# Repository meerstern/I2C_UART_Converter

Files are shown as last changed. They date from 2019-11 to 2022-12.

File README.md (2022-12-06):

# I2C_UART_Converter
I2C-UART Converter with Grove Connector

## 概要 
  * マイコンのI2CポートをUART通信ポートに変換するアダプタです
  * マイコンからI2Cデバイスとして制御し、UARTのボーレート設定、送信、受信処理をすることができます
  * I2C/UARTプロトコルブリッジ[SC16IS740][1]を搭載しています
  * I2CはGrove互換コネクタとなっており、3.3V/５Vの電源、通信に対応しています
  * I2C/UARTプロトコルブリッジSC16IS740は64bytesのバッファを内蔵しています
  * 7.3728MHzの水晶発振子を搭載しており、マイコンのメインクロックから独立してUARTのボーレート設定ができます  
  * デフォルトI2Cアドレスは8bit:0x9A(7bit:0x4D)です  

## 注意 
  * Arduino Uno以外の場合はサンプルコード内SC16IS750.cppの29行目付近のWire定義を必要に応じて変更してください  

## 販売サイト
  * [スイッチサイエンス][2]

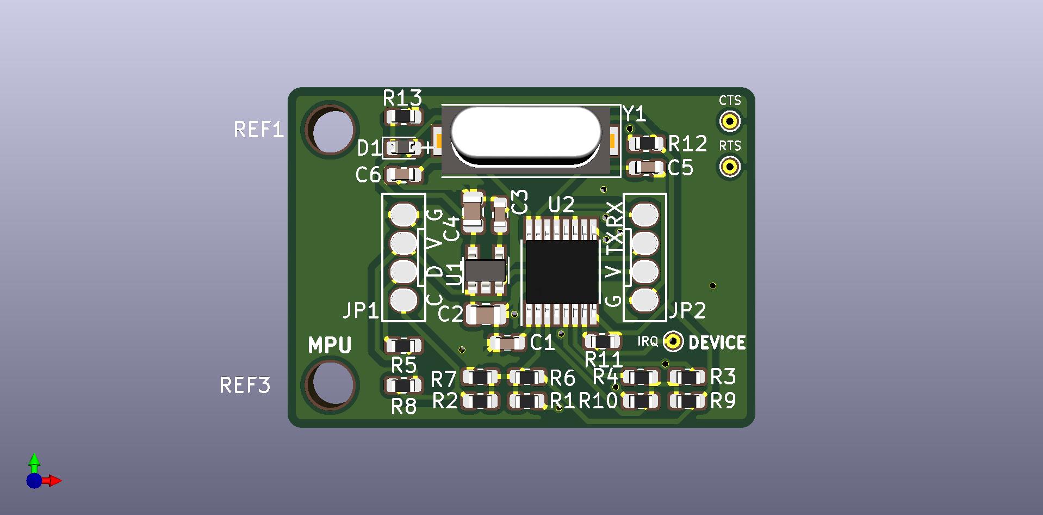
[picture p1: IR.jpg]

   
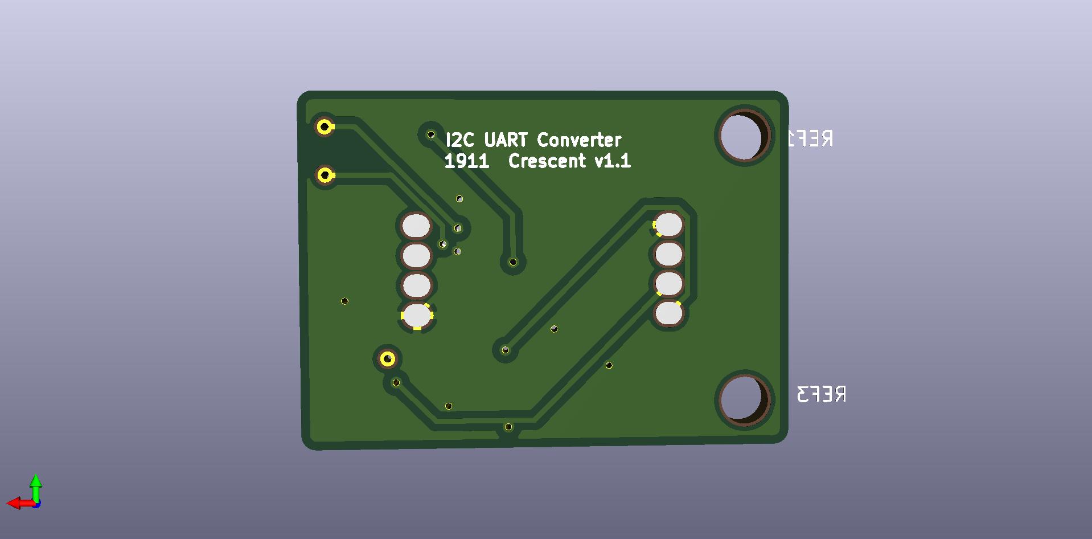
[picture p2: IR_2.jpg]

    
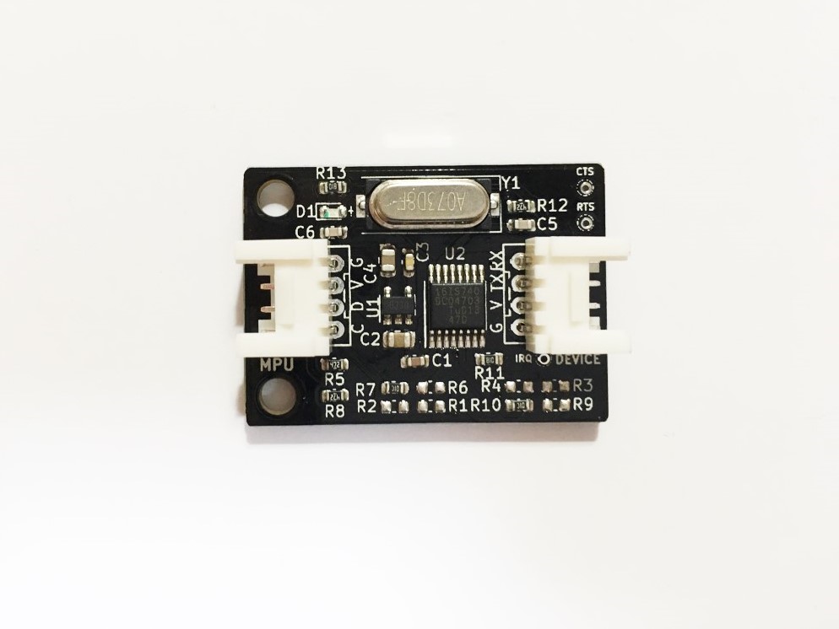
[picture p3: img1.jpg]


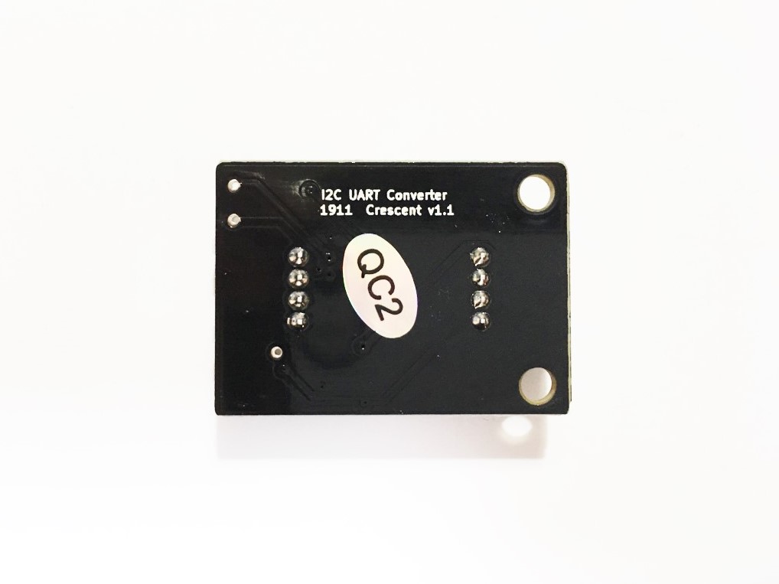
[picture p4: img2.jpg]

    
[1]: https://www.nxp.com/products/peripherals-and-logic/signal-chain/bridges/single-uart-with-i2c-bus-spi-interface-64-bytes-of-transmit-and-receive-fifos-irda-sir-built-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 "*1"
[2]: https://www.switch-science.com/products/6027
MIT Lisense

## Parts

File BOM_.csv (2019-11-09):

ID | 参照記号 | パッケージ | 数 | 名称 | Supplier and ref
2 | JP1,JP2 | GROVE | 2 | PINHD-1X4
3 | C1 | C_0603_1608Metric | 1 | 0.1u | C15725
4 | C2,C4 | C_0805_2012Metric | 2 | 10u | C15850
5 | C3 | C_0603_1608Metric | 1 | 0.01u | C57112
6 | C5,C6 | C_0603_1608Metric | 2 | 10p | C1634
7 | D1 | D_0603_1608Metric | 1 | LED | C72041
8 | R7,R10 | R_0603_1608Metric | 8 | 0
9 | R5,R8,R12 | R_0603_1608Metric | 3 | 4.7k
10 | R11,R13 | R_0603_1608Metric | 2 | 1k
11 | U1 | SOT-23-5 | 1 | LD3985M33R_SOT23
12 | Y1 | Crystal_SMD_HC49-SD | 1 | Crystal
16 | U2 | TSSOP-16_4.4x5mm_Pitch0.65mm | 1 | SC16IS740IPW

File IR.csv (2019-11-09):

ID | 参照記号 | パッケージ | 数 | 名称 | Supplier and ref
1 | REF3,REF1 | MountingHole_3.2mm_M3 | 2 | MountingHole_3.2mm_M3
2 | JP1,JP2 | GROVE | 2 | PINHD-1X4
3 | C1 | C_0603_1608Metric | 1 | 0.1u
4 | C2,C4 | C_0805_2012Metric | 2 | 10u
5 | C3 | C_0603_1608Metric | 1 | 0.01u
6 | C5,C6 | C_0603_1608Metric | 2 | 10p
7 | D1 | D_0603_1608Metric | 1 | LED
8 | R1,R2,R3,R4,R6,R7,R9,R10 | R_0603_1608Metric | 8 | 0
9 | R5,R8,R12 | R_0603_1608Metric | 3 | 4.7k
10 | R11,R13 | R_0603_1608Metric | 2 | 1k
11 | U1 | SOT-23-5 | 1 | LD3985M33R_SOT23
12 | Y1 | Crystal_SMD_HC49-SD | 1 | Crystal
13 | IRQ | TestPoint_THTPad_D1.0mm_Drill0.5mm | 1 | IRQ
14 | CTS | TestPoint_THTPad_D1.0mm_Drill0.5mm | 1 | CTS
15 | RTS | TestPoint_THTPad_D1.0mm_Drill0.5mm | 1 | RTS
16 | U2 | TSSOP-16_4.4x5mm_Pitch0.65mm | 1 | SC16IS740IPW

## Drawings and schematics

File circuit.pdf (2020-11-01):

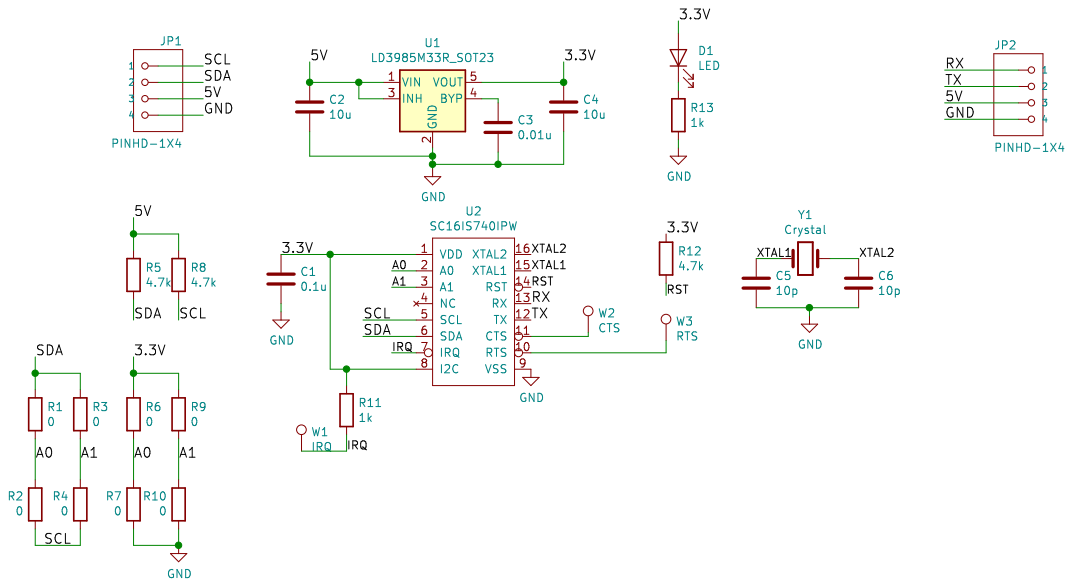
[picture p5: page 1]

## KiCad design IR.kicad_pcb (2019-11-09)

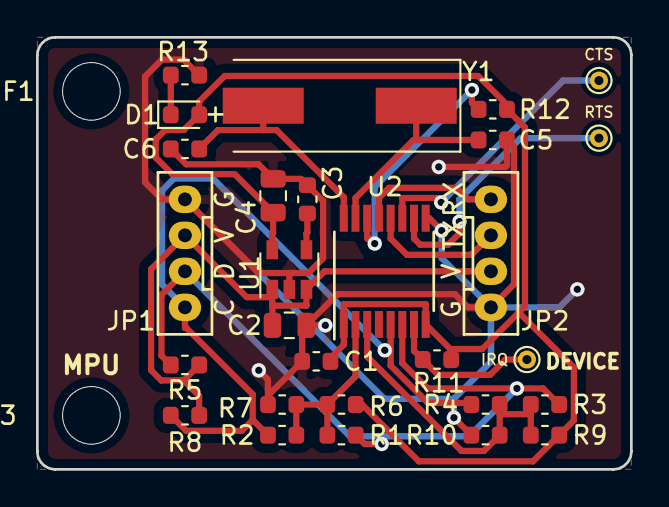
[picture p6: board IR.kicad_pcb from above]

Board: 2 copper layers, 33.0 x 24.0 mm, 30 parts (0 on the bottom side), 17 nets.

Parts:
C1: 0.1u; C_0603_1608Metric
C2, C4: 10u; C_0805_2012Metric
C3: 0.01u; C_0603_1608Metric
C5, C6: 10p; C_0603_1608Metric
CTS: CTS; TestPoint_THTPad_D1.0mm_Drill0.5mm
D1: LED; D_0603_1608Metric
IRQ: IRQ; TestPoint_THTPad_D1.0mm_Drill0.5mm
JP1, JP2: PINHD-1X4; GROVE
R1, R2, R3, R4, R6, R7, R9, R10: 0; R_0603_1608Metric
R5, R8, R12: 4.7k; R_0603_1608Metric
R11, R13: 1k; R_0603_1608Metric
REF1, REF3: MountingHole_3.2mm_M3
RTS: RTS; TestPoint_THTPad_D1.0mm_Drill0.5mm
U1: LD3985M33R_SOT23; SOT-23-5
U2: SC16IS740IPW; TSSOP-16_4.4x5mm_Pitch0.65mm
Y1: Crystal; Crystal_SMD_HC49-SD

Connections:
/3.3V: C1.1, C4.1, D1.2, R6.1, R9.1, R11.1, R12.1, U1.5, U2.1, U2.8
/5V: C2.1, JP1.3, JP2.3, R5.1, R8.1, U1.1, U1.3
/A0: R1.2, R2.2, R6.2, R7.2, U2.2
/A1: R3.2, R4.2, R9.2, R10.2, U2.3
/IRQ: IRQ.1, R11.2, U2.7
/RST: R12.2, U2.14
/RX: JP2.1, U2.13
/SCL: JP1.1, R2.1, R4.1, R8.2, U2.5
/SDA: JP1.2, R1.1, R3.1, R5.2, U2.6
/TX: JP2.2, U2.12
/XTAL1: C5.1, U2.15, Y1.1
/XTAL2: C6.1, U2.16, Y1.2
GND: C1.2, C2.2, C3.2, C4.2, C5.2, C6.2, JP1.4, JP2.4, R7.1, R10.1, R13.2, U1.2, U2.9
unnamed: C3.1, U1.4
unnamed: D1.1, R13.1
unnamed: RTS.1, U2.10
unnamed: CTS.1, U2.11

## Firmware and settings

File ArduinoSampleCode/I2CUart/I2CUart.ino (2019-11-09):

#include <Wire.h>

#include <string.h>
#include <SPI.h>
#include "SC16IS750.h"


SC16IS750 i2cuart = SC16IS750(SC16IS750_PROTOCOL_I2C,SC16IS750_ADDRESS_BB);

//Connect TX and RX with a wire and run this sketch

void setup() 
{
    Serial.begin(9600);

    // UART to Serial Bridge Initialization
    i2cuart.begin(9600);               //baudrate setting
    Serial.println("Init OK");
    if (i2cuart.ping()!=1) {
        Serial.println("device not found");
        while(1);
    } else {
        Serial.println("device found");
    }
    Serial.println("start serial communication");
    


};

void loop() 
{
   
    i2cuart.write(0x55);
    while(i2cuart.available()==0);
    if (i2cuart.read()!=0x55) {
        Serial.println("serial communication error 1");
        while(1);
    }
    else{
      Serial.println("serial communication OK 1");
    }   
    delay(500);
    
    i2cuart.write(0x0A);
    while(i2cuart.available()==0);
    if (i2cuart.read()!=0x0A) {
        Serial.println("serial communication error 2");
        while(1);
    }
    else{
      Serial.println("serial communication OK 2");
    }   
    
    delay(500);
      
     
  
  

  
};

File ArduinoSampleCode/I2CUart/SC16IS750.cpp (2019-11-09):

/*
Description:
This is a example code for Sandbox Electronics' I2C/SPI to UART bridge module.
You can get one of those products on
http://sandboxelectronics.com

Version:
V0.1

Release Date:
2014-02-16

Author:
Tiequan Shao          info@sandboxelectronics.com

Lisence:
CC BY-NC-SA 3.0

Please keep the above information when you use this code in your project.
*/


//#define SC16IS750_DEBUG_PRINT
#include "SC16IS750.h"
#include <SPI.h>
#include <Wire.h>


#ifdef __AVR__
 #define WIRE Wire
#else // Arduino Due
 #define WIRE Wire1
#endif


SC16IS750::SC16IS750(uint8_t prtcl, uint8_t addr_sspin)
{
    protocol = prtcl;
    if ( protocol == SC16IS750_PROTOCOL_I2C ) {
		device_address_sspin = (addr_sspin>>1);
	} else {
		device_address_sspin = addr_sspin;
	}
	peek_flag = 0;
//	timeout = 1000;
}


void SC16IS750::begin(uint32_t baud)
{
  //Serial.println("1111111111111111");
	if ( protocol == SC16IS750_PROTOCOL_I2C) {
	      //Serial.println("22222222222222");
        WIRE.begin();
    } else {
	//Serial.println("3333333333333333333");
		::pinMode(device_address_sspin, OUTPUT);
   	    ::digitalWrite(device_address_sspin, HIGH);
		SPI.setDataMode(SPI_MODE0);
		SPI.setClockDivider(SPI_CLOCK_DIV4);
		SPI.setBitOrder(MSBFIRST);
		SPI.begin();
		//SPI.setClockDivider(32);

	//Serial.println("4444444444444444444");
	};
    ResetDevice();
    FIFOEnable(1);
	  SetBaudrate(baud);
    SetLine(8,0,1);
}

int SC16IS750::available(void)
{
    return FIFOAvailableData();
}

int SC16IS750::read(void)
{
	if ( peek_flag == 0) {
		return ReadByte();
	} else {
		peek_flag = 0;
		return peek_buf;
	}
}

size_t SC16IS750::write(uint8_t val)
{
    WriteByte(val);
}

void SC16IS750::pinMode(uint8_t pin, uint8_t i_o)
{
    GPIOSetPinMode(pin, i_o);
}

void SC16IS750::digitalWrite(uint8_t pin, uint8_t value)
{
    GPIOSetPinState(pin, value);
}

uint8_t SC16IS750::digitalRead(uint8_t pin)
{
   return GPIOGetPinState(pin);
}


uint8_t SC16IS750::ReadRegister(uint8_t reg_addr)
{
    uint8_t result;
	if ( protocol == SC16IS750_PROTOCOL_I2C ) {  // register read operation via I2C

		WIRE.beginTransmission(device_address_sspin);
		WIRE.write((reg_addr<<3));
  	WIRE.endTransmission(0);
		WIRE.requestFrom(device_address_sspin,(uint8_t)1);
		result = WIRE.read();
	} else if (protocol == SC16IS750_PROTOCOL_SPI) {                                   //register read operation via SPI
		::digitalWrite(device_address_sspin, LOW);
		delayMicroseconds(10);
		SPI.transfer(0x80|(reg_addr<<3));
		result = SPI.transfer(0xff);
		delayMicroseconds(10);
		::digitalWrite(device_address_sspin, HIGH);
	}

	return result;

}

void SC16IS750::WriteRegister(uint8_t reg_addr, uint8_t val)
{
    if ( protocol == SC16IS750_PROTOCOL_I2C ) {  // register read operation via I2C
		WIRE.beginTransmission(device_address_sspin);
		WIRE.write((reg_addr<<3));
  	WIRE.write(val);
		WIRE.endTransmission(1);
	} else {
		::digitalWrite(device_address_sspin, LOW);
		delayMicroseconds(10);
		SPI.transfer(reg_addr<<3);
		SPI.transfer(val);
		delayMicroseconds(10);
		::digitalWrite(device_address_sspin, HIGH);

	}


    return ;
}

int16_t SC16IS750::SetBaudrate(uint32_t baudrate) //return error of baudrate parts per thousand
{
    uint16_t divisor;
    uint8_t prescaler;
    uint32_t actual_baudrate;
    int16_t error;
    uint8_t temp_lcr;
    if ( (ReadRegister(SC16IS750_REG_MCR)&0x80) == 0) { //if prescaler==1
        prescaler = 1;
    } else {
        prescaler = 4;
    }

    divisor = (SC16IS750_CRYSTCAL_FREQ/prescaler)/(baudrate*16);

    temp_lcr = ReadRegister(SC16IS750_REG_LCR);
    temp_lcr |= 0x80;
    WriteRegister(SC16IS750_REG_LCR,temp_lcr);
    //write to DLL
    WriteRegister(SC16IS750_REG_DLL,(uint8_t)divisor);
    //write to DLH
    WriteRegister(SC16IS750_REG_DLH,(uint8_t)(divisor>>8));
    temp_lcr &= 0x7F;
    WriteRegister(SC16IS750_REG_LCR,temp_lcr);


    actual_baudrate = (SC16IS750_CRYSTCAL_FREQ/prescaler)/(16*divisor);
    error = ((float)actual_baudrate-baudrate)*1000/baudrate;
#ifdef  SC16IS750_DEBUG_PRINT
    Serial.print("Desired baudrate: ");
    Serial.println(baudrate,DEC);
    Serial.print("Calculated divisor: ");
    Serial.println(divisor,DEC);
    Serial.print("Actual baudrate: ");
    Serial.println(actual_baudrate,DEC);
    Serial.print("Baudrate error: ");
    Serial.println(error,DEC);
#endif

    return error;

}

void SC16IS750::SetLine(uint8_t data_length, uint8_t parity_select, uint8_t stop_length )
{
    uint8_t temp_lcr;
    temp_lcr = ReadRegister(SC16IS750_REG_LCR);
    temp_lcr &= 0xC0; //Clear the lower six bit of LCR (LCR[0] to LCR[5]
#ifdef  SC16IS750_DEBUG_PRINT
    Serial.print("LCR Register:0x");
    Serial.println(temp_lcr,DEC);
#endif
    switch (data_length) {            //data length settings
        case 5:
            break;
        case 6:
            temp_lcr |= 0x01;
            break;
        case 7:
            temp_lcr |= 0x02;
            break;
        case 8:
            temp_lcr |= 0x03;
            break;
        default:
            temp_lcr |= 0x03;
            break;
    }

    if ( stop_length == 2 ) {
        temp_lcr |= 0x04;
    }

    switch (parity_select) {            //parity selection length settings
        case 0:                         //no parity
             break;
        case 1:                         //odd parity
            temp_lcr |= 0x08;
            break;
        case 2:                         //even parity
            temp_lcr |= 0x18;
            break;
        case 3:                         //force '1' parity
            temp_lcr |= 0x03;
            break;
        case 4:                         //force '0' parity
            break;
        default:
            break;
    }

    WriteRegister(SC16IS750_REG_LCR,temp_lcr);
}

void SC16IS750::GPIOSetPinMode(uint8_t pin_number, uint8_t i_o)
{
    uint8_t temp_iodir;

    temp_iodir = ReadRegister(SC16IS750_REG_IODIR);
    if ( i_o == OUTPUT ) {
      temp_iodir |= (0x01 << pin_number);
    } else {
      temp_iodir &= (uint8_t)~(0x01 << pin_number);
    }

    WriteRegister(SC16IS750_REG_IODIR, temp_iodir);
    return;
}

void SC16IS750::GPIOSetPinState(uint8_t pin_number, uint8_t pin_state)
{
    uint8_t temp_iostate;

    temp_iostate = ReadRegister(SC16IS750_REG_IOSTATE);
    if ( pin_state == 1 ) {
      temp_iostate |= (0x01 << pin_number);
    } else {
      temp_iostate &= (uint8_t)~(0x01 << pin_number);
    }

    WriteRegister(SC16IS750_REG_IOSTATE, temp_iostate);
    return;
}


uint8_t SC16IS750::GPIOGetPinState(uint8_t pin_number)
{
    uint8_t temp_iostate;

    temp_iostate = ReadRegister(SC16IS750_REG_IOSTATE);
    if ( temp_iostate & (0x01 << pin_number)== 0 ) {
      return 0;
    }
    return 1;
}

uint8_t SC16IS750::GPIOGetPortState(void)
{

    return ReadRegister(SC16IS750_REG_IOSTATE);

}

void SC16IS750::GPIOSetPortMode(uint8_t port_io)
{
    WriteRegister(SC16IS750_REG_IODIR, port_io);
    return;
}
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

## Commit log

2019-11-09 Upload data
    [BOM_.csv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]
2019-11-09 Add sample code
2020-11-01 Update circuit
